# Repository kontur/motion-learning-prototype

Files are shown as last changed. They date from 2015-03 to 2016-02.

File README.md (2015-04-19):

#Motion learning
Prototype for wearable device enhancing motion based learning through sensory feedback.

The idea of this wearable device is to allow the wearer to rely on a multitude of additional sensory information when learning or repeating physical motion. This prototype is designed as a wrist-worn band that gives light, sound and vibration feedback.

Furthermore, the planned desktop interface allows users to record, compare and visualize their movement patterns.

##WIP
Codebase and physical design currently heavily WIP.

##Credits
Many parts of this project are based on open software or hardware. Arduino, Processing and Eagle have been used for the various aspects of the project. In more details:

* The led shield uses the [Adafruit PWM servo driver library](https://github.com/adafruit/Adafruit-PWM-Servo-Driver-Library)
* The Sparkfun IMU shields and their libraries [LSM9](https://github.com/sparkfun/LSM9DS0_Breakout) and [6DoF](https://github.com/sparkfun/IMU_Digital_Combo_Board)
* The project uses [this](http://bildr.org/2012/03/stable-orientation-digital-imu-6dof-arduino/) modification of [Varesano's FreeIMU](www.varesano.net/projects/hardware/FreeIMU) libraries for motion sensor reading
* [HSBColor](https://github.com/julioterra/HSB_Color) library for Arduino for color conversions
* [Toxiclibs](http://toxiclibs.org/) was used on the Processing visualization
* [controlP5](http://www.sojamo.de/libraries/controlP5/) was used in the Processing interface
* [Javastat](http://www2.thu.edu.tw/~wenwei/javastat/doc/) libraries were used for some portions in the software dealing with comparing motion patterns

###Authors
Johannes Neumeier, Jana Pejoska

###Acknowledgments
Project created in spring 2015 at Aalto Media Lab, in the course Prototyping Experience under guidance from Michihito Mizutani.

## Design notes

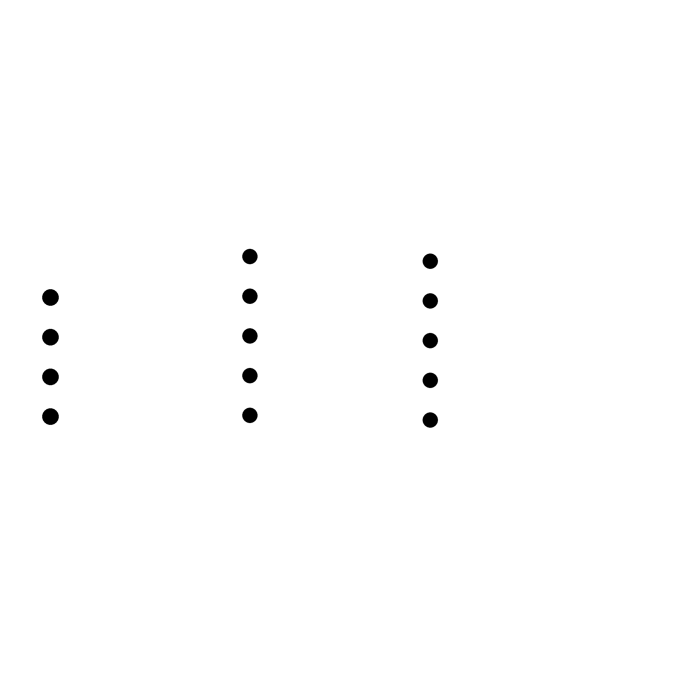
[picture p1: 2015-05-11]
eagle/ledshields_v2/_drill.png

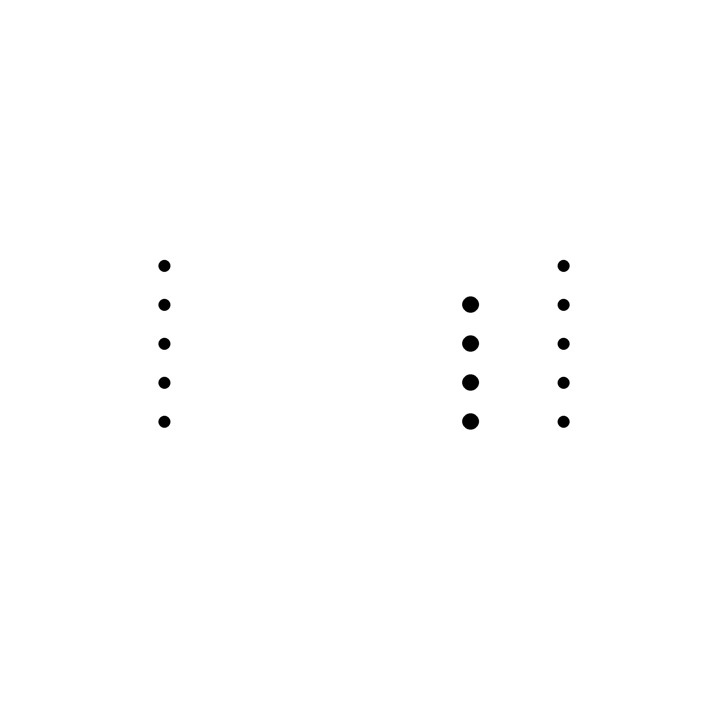
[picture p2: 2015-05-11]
eagle/ledshield/drill.png

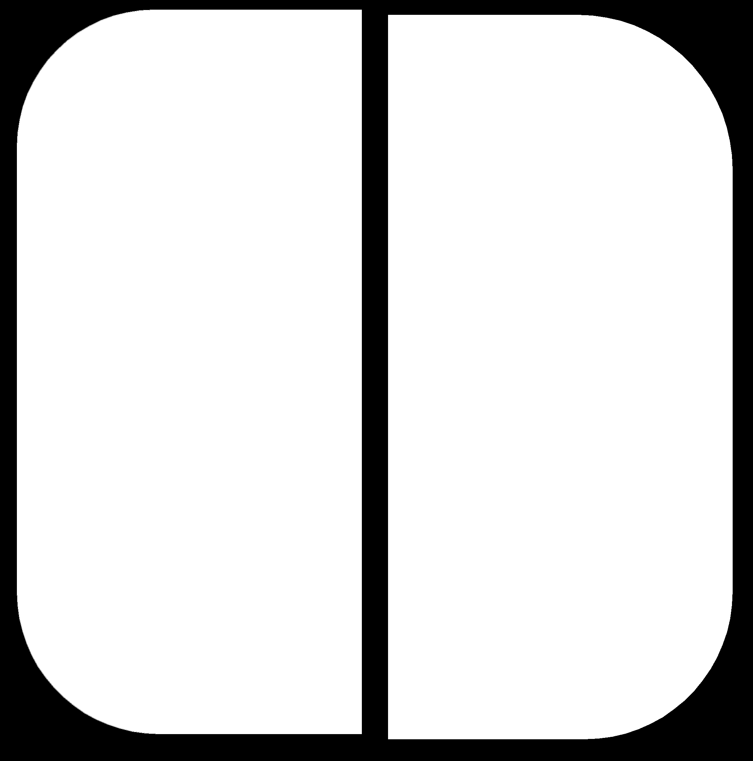
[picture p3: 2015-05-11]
eagle/ledshields_v2/_cut.png

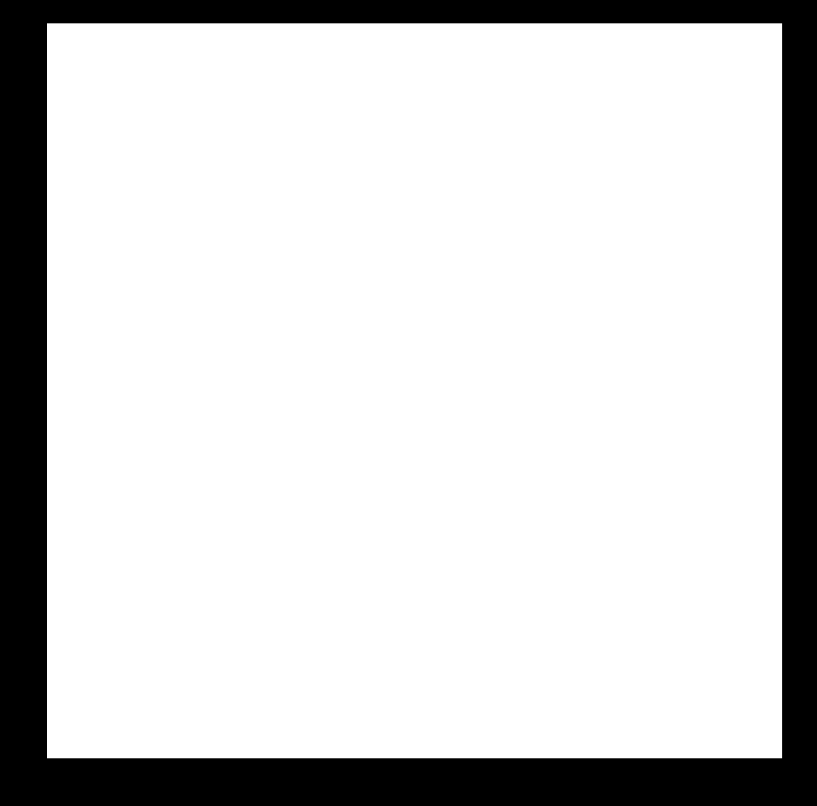
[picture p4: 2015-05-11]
eagle/ledshield/dimension.png

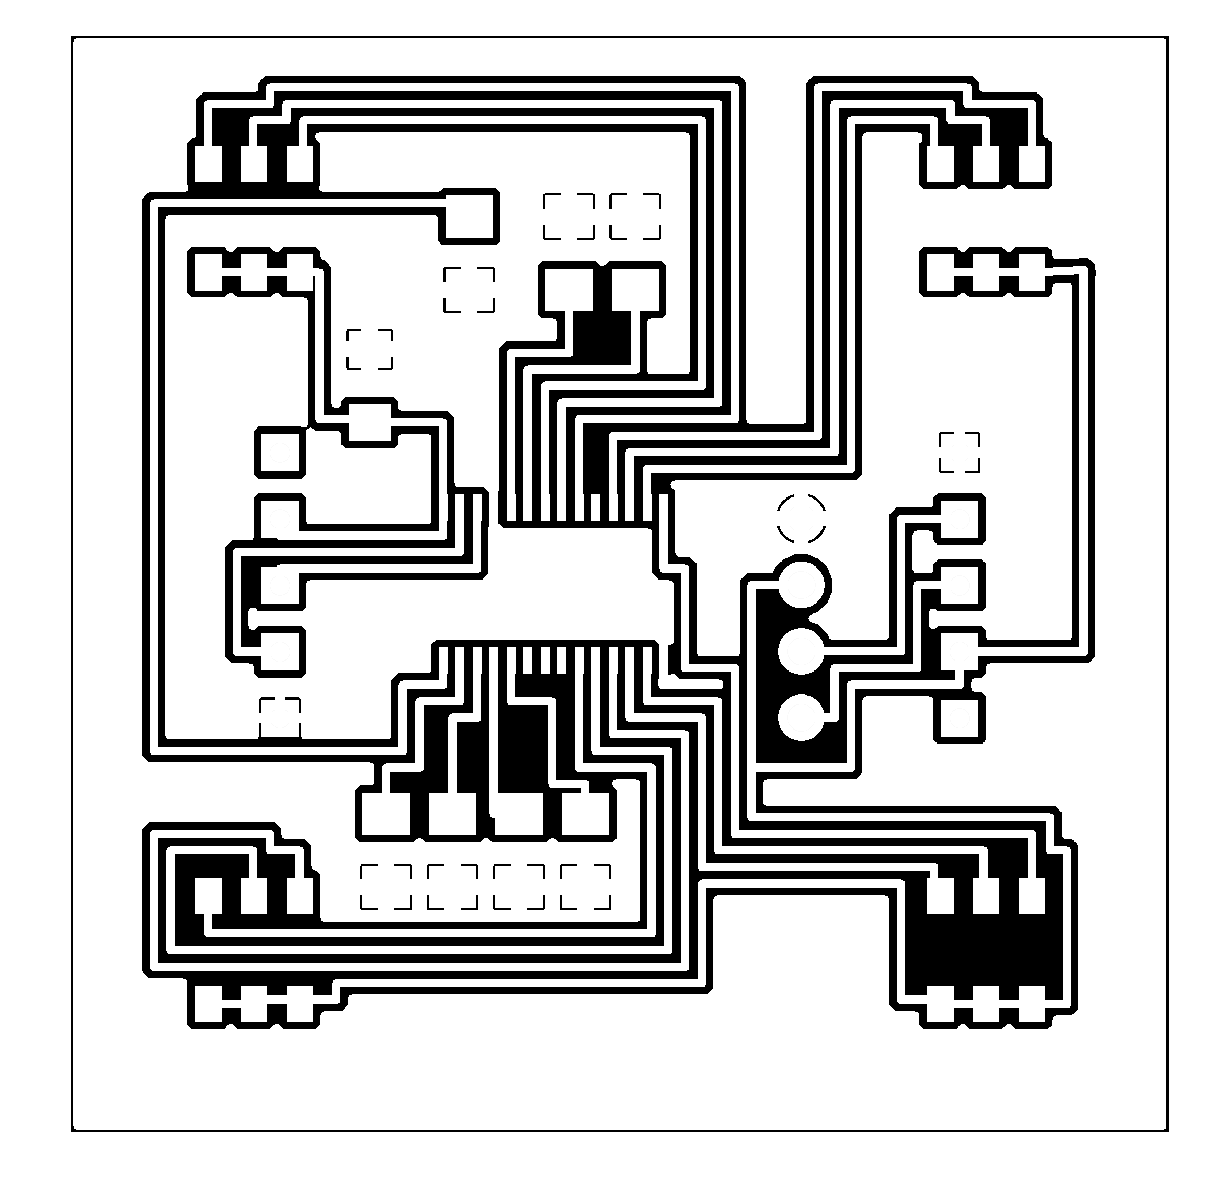
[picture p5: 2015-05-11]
eagle/ledshield/top_0mm3.png

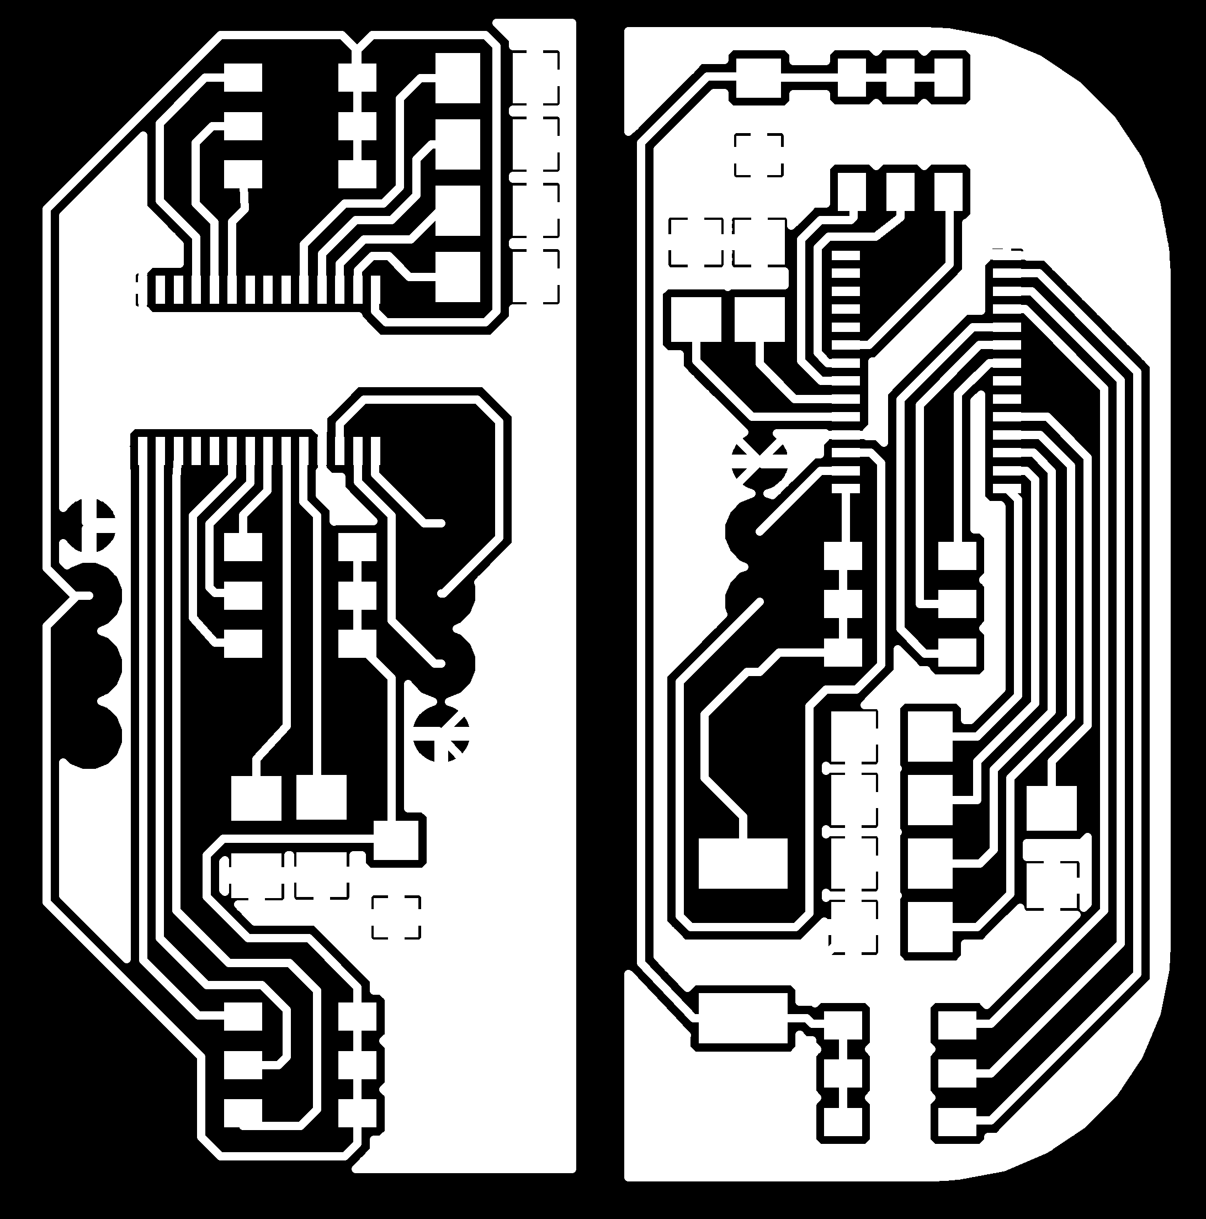
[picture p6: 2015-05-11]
eagle/ledshields_v2/_traces.png

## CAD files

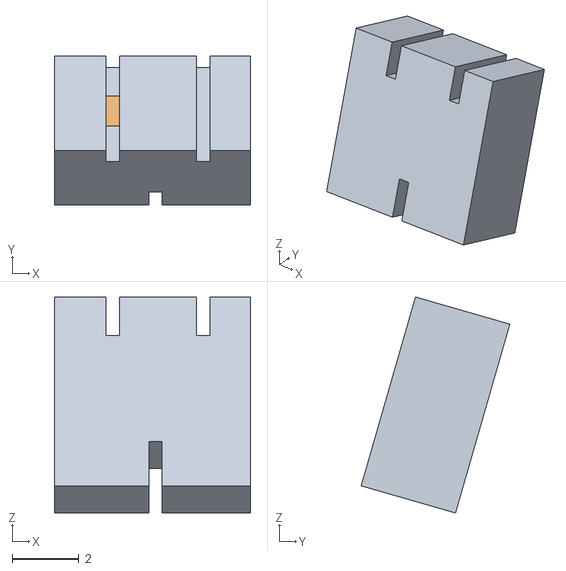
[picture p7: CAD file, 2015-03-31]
processing/Kinemata/data/dma.obj
5.87 x 4.44 x 6.45
polySurface3_group1

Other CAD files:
eagle/kinemata/110mAhBattery.dxf

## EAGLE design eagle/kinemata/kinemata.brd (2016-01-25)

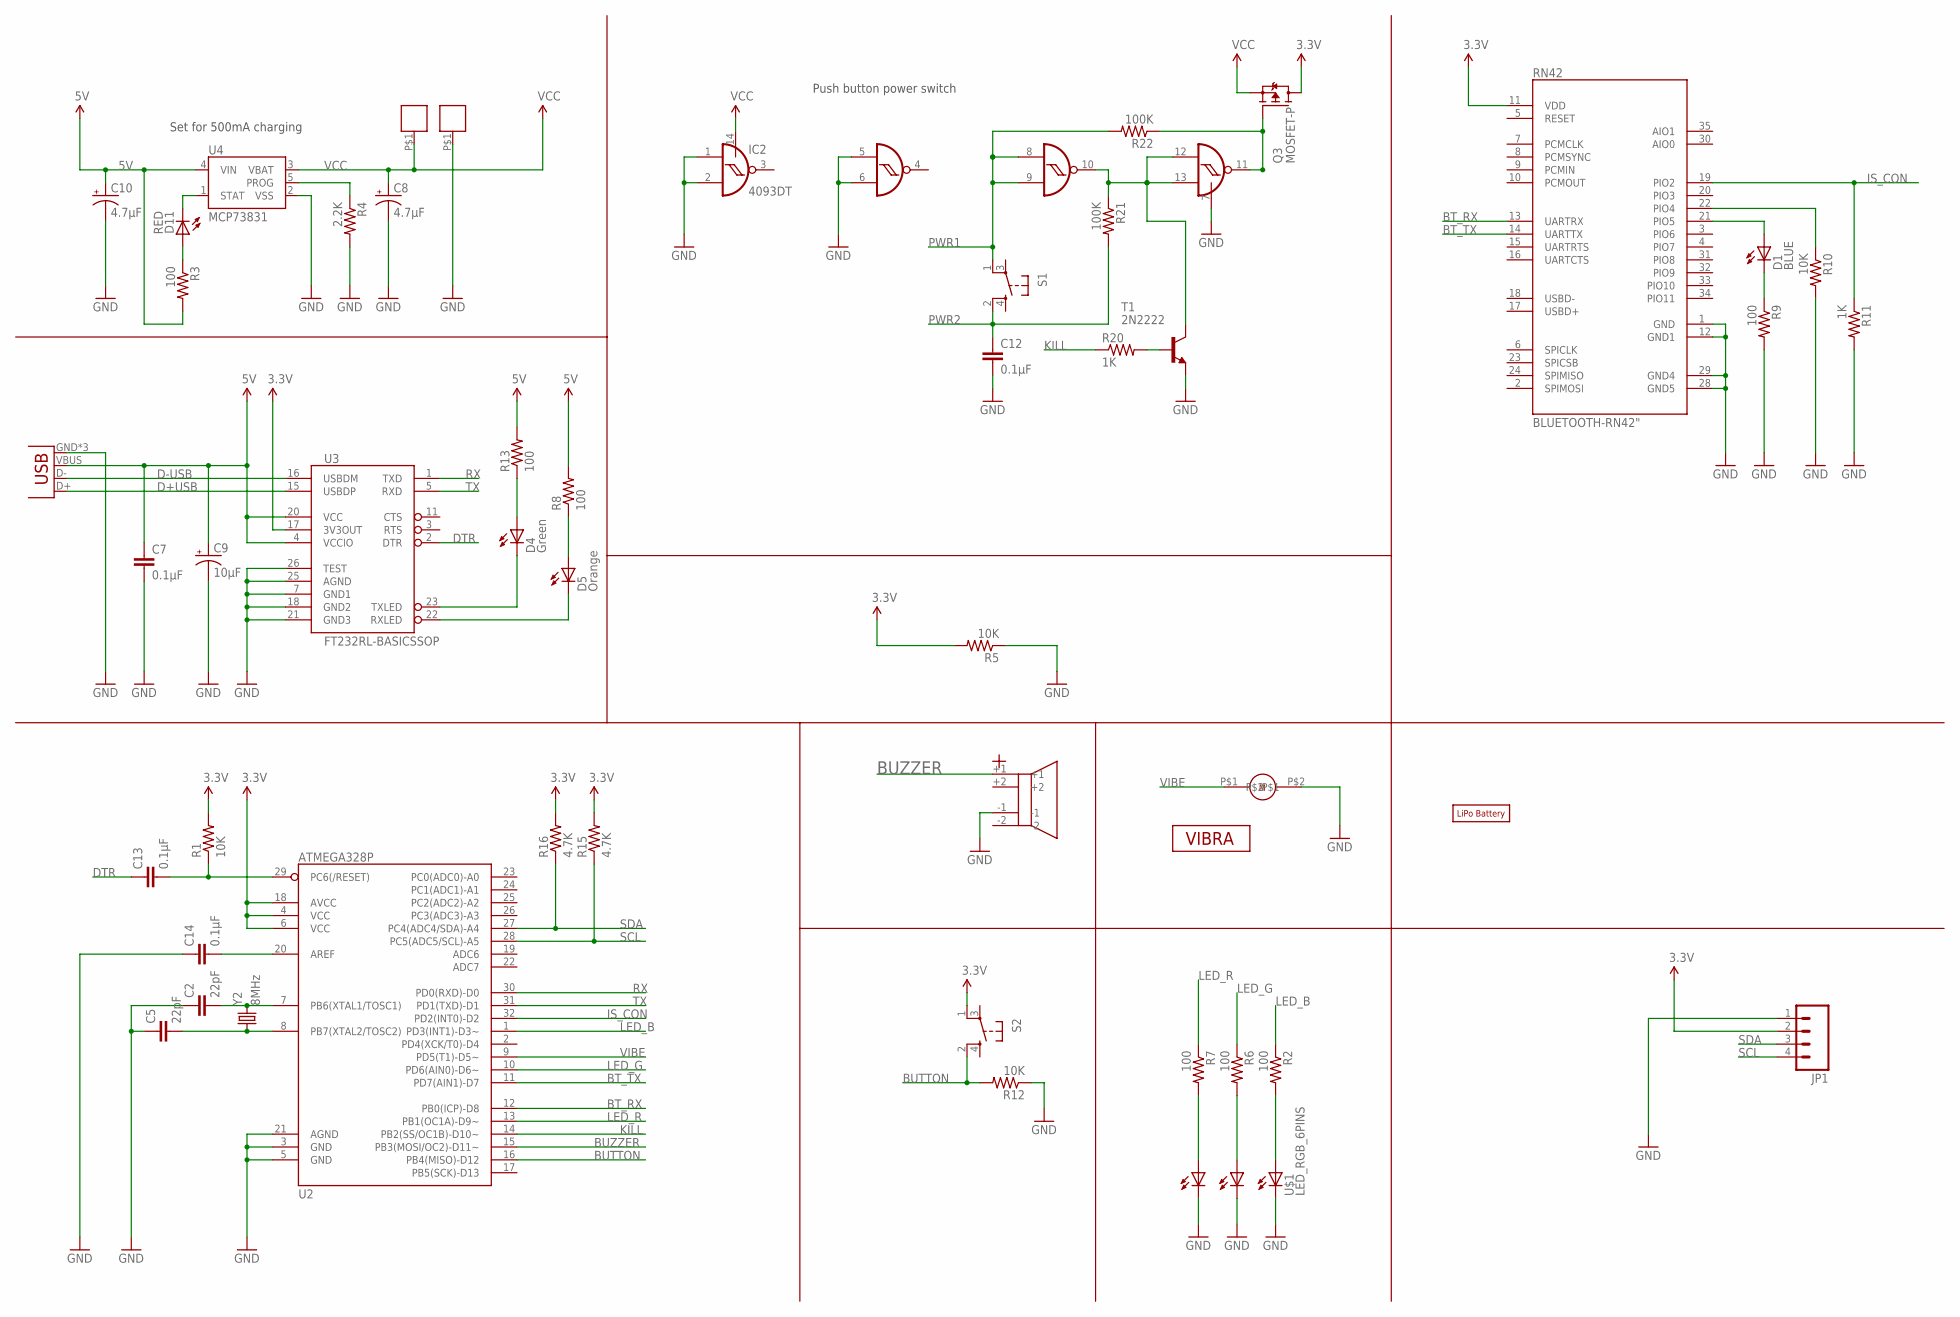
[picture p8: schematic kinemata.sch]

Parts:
BAT+2: LIPO_PAD
BAT-1: LIPO_PAD
C2, C5: 22pF; 1206
C7, C12, C13, C14: 0.1µF; 1206
C8, C10: 4.7µF; EIA3216
C9: 10µF; EIA3216
D1: BLUE; LED-1206
D4: Green; LED-1206
D5: Orange; LED-1206
D11: RED; LED-1206
IC2: 4093DT; MC14093B-TSSOP14
JP1: M04LONGPADS; 1X04_LONGPADS
JP6: USB-MICROB
Q3: MOSFET-P; SOT23
R1, R5, R10, R12: 10K; 1206
R2, R3, R6, R7, R8, R9, R13: 100; 1206
R4: 2.2K; 1206
R11, R20: 1K; 1206
R15, R16: 4.7K; 1206
R21, R22: 100K; 1206
RN42: BLUETOOTH-RN42"; RN42
S1, S2: TAC_SWITCH_SIDEWAY; TACTILE_SWITCH_ANGLE_SMD
T1: 2N2222; TO92-EBC-OVAL
U2: ATMEGA328P; TQFP32-08
U3: FT232RL-BASICSSOP; SSOP28DB
U4: MCP73831; SOT23-5
U$1: LED_RGB_6PINS
U$2: LIPO_BATTERY110MAH; LIPO_BATTERY_110MAH
U$3: BUZZER_4PINS; FARNELL_BUZZER_MAGNETIC_SMD_3V_2215091
U$4: VIBRATION_MOTOR_SHAPE
U$5: VIBRATION_MOTOR; VIBRATION_MOTOR_CABLE
Y2: 8MHz; CRYSTAL_8MHZ_SMD_FARNELL_2101329

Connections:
3.3V: JP1.2, Q3.3 (D), R1.2, R5.2, R15.2, R16.2, RN42.11 (VDD), S2.1 (A2), U2.4 (VCC), U2.6 (VCC), U2.18 (AVCC), U3.17 (3V3OUT)
5V: C7.1, C9.A (+), C10.A (+), JP6.VBUS, R3.2, R8.2, R13.2, U3.4 (VCCIO), U3.20 (VCC), U4.4 (VIN)
BT_RX: RN42.13 (UARTRX), U2.12 (PB0(ICP)-D8)
BT_TX: RN42.14 (UARTTX), U2.11 (PD7(AIN1)-D7)
BUTTON: R12.2, S2.2 (B2), U2.16 (PB4(MISO)-D12)
BUZZER: U2.15 (PB3(MOSI/OC2)-D11~), U$3.+1
D+USB: JP6.D+, U3.15 (USBDP)
D-USB: JP6.D-, U3.16 (USBDM)
DTR: C13.1, U3.2 (DTR)
GND: BAT-1.P$1, C2.1, C5.1, C7.2, C8.C (-), C9.C (-), C10.C (-), C12.2, C14.1, IC2.1, IC2.2, IC2.5, IC2.6, IC2.7, JP1.1, JP6.GND, JP6.MT1 (GND), JP6.MT2 (GND), R4.2, R5.1, R9.2, R10.2, R11.2, R12.1, RN42.1 (GND), RN42.12 (GND1), RN42.28 (GND5), RN42.29 (GND4), T1.E, U2.3 (GND), U2.5 (GND), U2.21 (AGND), U3.7 (GND1), U3.18 (GND2), U3.21 (GND3), U3.25 (AGND), U3.26 (TEST), U4.2 (VSS), U$1.BC, U$1.GC, U$1.RC, U$3.-1, U$5.P$2
IS_CON: R11.1, RN42.19 (PIO2), U2.32 (PD2(INT0)-D2)
KILL: R20.1, U2.14 (PB2(SS/OC1B)-D10~)
LED_B: R2.1, U2.1 (PD3(INT1)-D3~)
LED_G: R6.1, U2.10 (PD6(AIN0)-D6~)
LED_R: R7.1, U2.13 (PB1(OC1A)-D9~)
unnamed: R7.2, U$1.BA
unnamed: R2.2, U$1.GA
unnamed: D11.A, R3.1
unnamed: R6.2, U$1.RA
unnamed: D4.A, R13.1
unnamed: D5.A, R8.1
unnamed: R10.1, RN42.22 (PIO4)
unnamed: D1.A, RN42.21 (PIO5)
unnamed: C5.2, U2.8 (PB7(XTAL2/TOSC2)), Y2.P$1 (1)
unnamed: C2.2, U2.7 (PB6(XTAL1/TOSC1)), Y2.P$2 (2)
unnamed: D1.C, R9.1
unnamed: C13.2, R1.1, U2.29 (PC6(/RESET))
unnamed: C14.2, U2.20 (AREF)
unnamed: IC2.10, IC2.12, IC2.13, R21.1, T1.C
unnamed: R20.2, T1.B
unnamed: IC2.11, Q3.1 (G), R22.1
PROG: R4.1, U4.5 (PROG)
PWR1: IC2.8, IC2.9, R22.2, S1.1 (A2)
PWR2: C12.1, R21.2, S1.2 (B2)
RX: U2.30 (PD0(RXD)-D0), U3.1 (TXD)
RXLED: D5.C, U3.22 (RXLED)
SCL: JP1.4, R15.1, U2.28 (PC5(ADC5/SCL)-A5)
SDA: JP1.3, R16.1, U2.27 (PC4(ADC4/SDA)-A4)
STAT: D11.C, U4.1 (STAT)
TX: U2.31 (PD1(TXD)-D1), U3.5 (RXD)
TXLED: D4.C, U3.23 (TXLED)
VCC: BAT+2.P$1, C8.A (+), IC2.14, Q3.2 (S), U4.3 (VBAT)
VIBE: U2.9 (PD5(T1)-D5~), U$5.P$1

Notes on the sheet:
Set for 500mA charging
Push button power switch

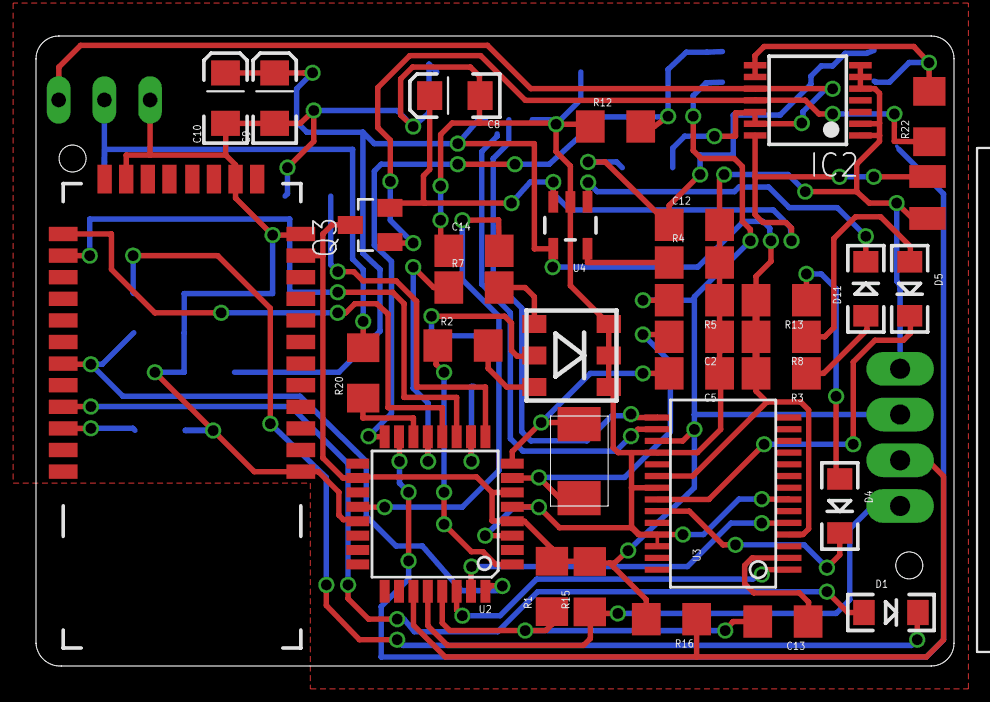
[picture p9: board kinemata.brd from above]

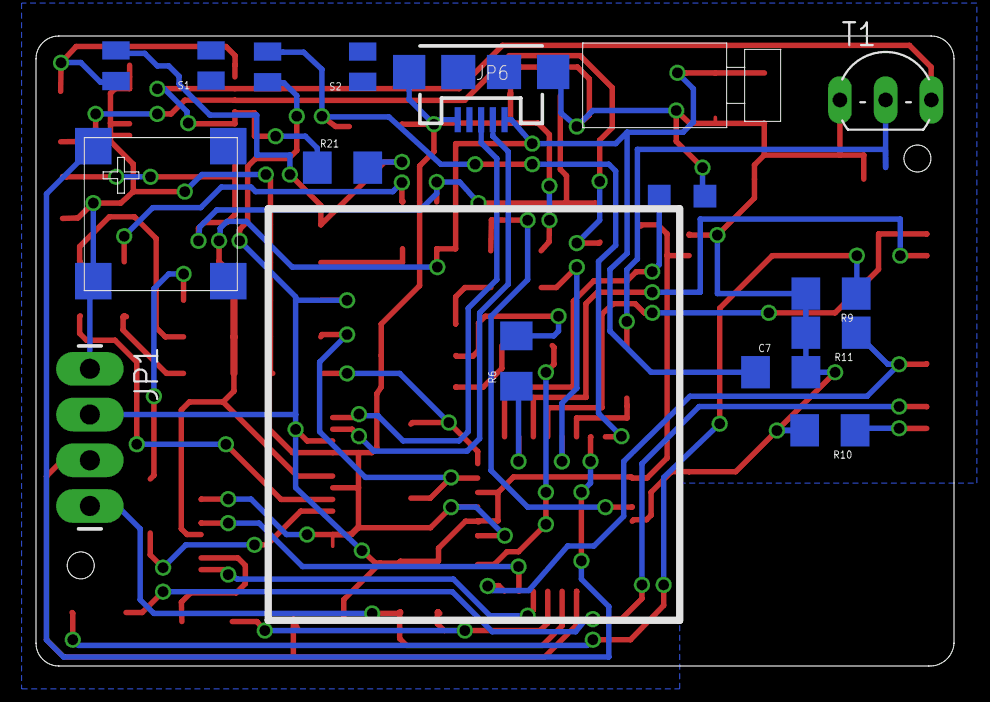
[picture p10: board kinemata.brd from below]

Board: 2 copper layers, 51.0 x 35.0 mm, 50 parts (14 on the bottom side), 43 nets.

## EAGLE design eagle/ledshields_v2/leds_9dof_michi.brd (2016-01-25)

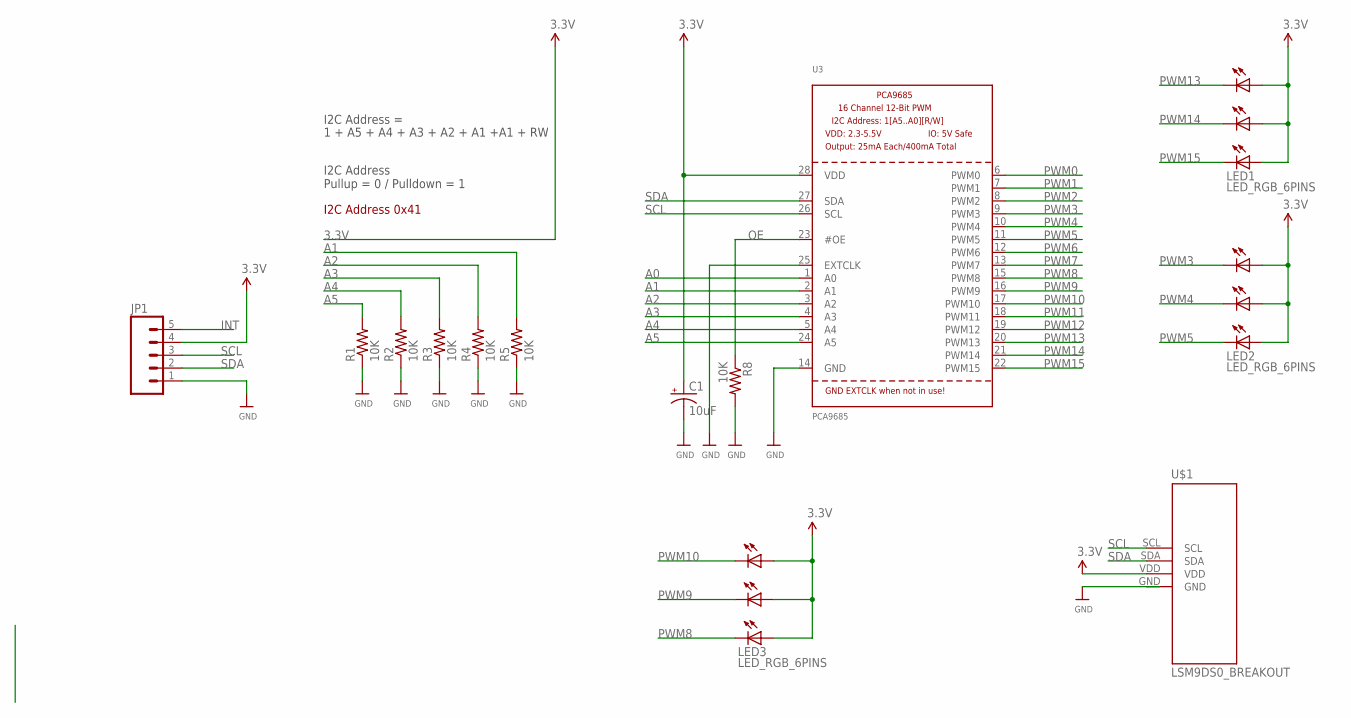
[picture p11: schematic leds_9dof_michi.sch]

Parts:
C1: 10uF; EIA3216
JP1: M05PTH; 1X05
LED1, LED2, LED3: LED_RGB_6PINS
R1, R2, R3, R4, R5, R8: 10K; 1206
U3: PCA9685; TSSOP28
U$1: LSM9DS0_BREAKOUT

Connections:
3.3V: C1.A (+), JP1.4, LED1.BA, LED1.GA, LED1.RA, LED2.BA, LED2.GA, LED2.RA, LED3.BA, LED3.GA, LED3.RA, U3.28 (VDD), U$1.VDD
A0: U3.1 (A0)
A1: R5.2, U3.2 (A1)
A2: R4.2, U3.3 (A2)
A3: R3.2, U3.4 (A3)
A4: R2.2, U3.5 (A4)
A5: R1.2, U3.24 (A5)
GND: C1.C (-), JP1.1, R1.1, R2.1, R3.1, R4.1, R5.1, R8.2, U3.14 (GND), U3.25 (EXTCLK), U$1.GND
INT: JP1.5
OE: R8.1, U3.23 (#OE)
PWM0: U3.6 (PWM0)
PWM1: U3.7 (PWM1)
PWM2: U3.8 (PWM2)
PWM3: LED2.BC, U3.9 (PWM3)
PWM4: LED2.RC, U3.10 (PWM4)
PWM5: LED2.GC, U3.11 (PWM5)
PWM6: U3.12 (PWM6)
PWM7: U3.13 (PWM7)
PWM8: LED3.GC, U3.15 (PWM8)
PWM9: LED3.RC, U3.16 (PWM9)
PWM10: LED3.BC, U3.17 (PWM10)
PWM11: U3.18 (PWM11)
PWM12: U3.19 (PWM12)
PWM13: LED1.BC, U3.20 (PWM13)
PWM14: LED1.RC, U3.21 (PWM14)
PWM15: LED1.GC, U3.22 (PWM15)
SCL: JP1.3, U3.26 (SCL), U$1.SCL
SDA: JP1.2, U3.27 (SDA), U$1.SDA

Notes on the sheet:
1 + A5 + A4 + A3 + A2 + A1 +A1 + RW
I2C Address =
I2C Address Pullup = 0 / Pulldown = 1
I2C Address 0x41

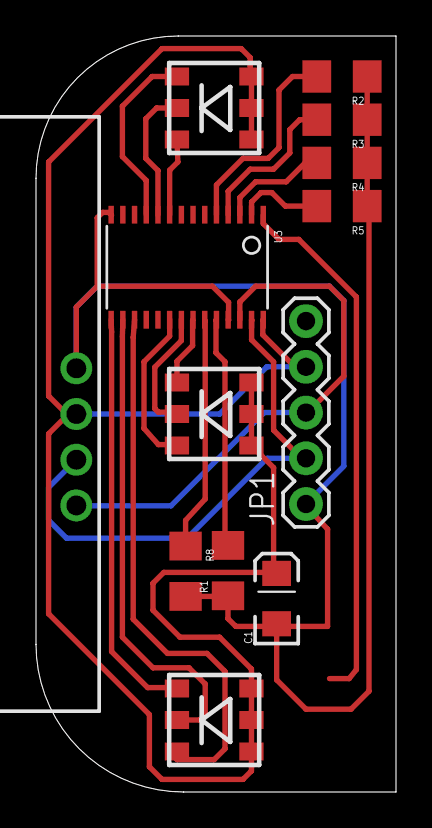
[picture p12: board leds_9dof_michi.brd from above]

Board: 2 copper layers, 20.0 x 42.0 mm, 13 parts (0 on the bottom side), 19 nets.

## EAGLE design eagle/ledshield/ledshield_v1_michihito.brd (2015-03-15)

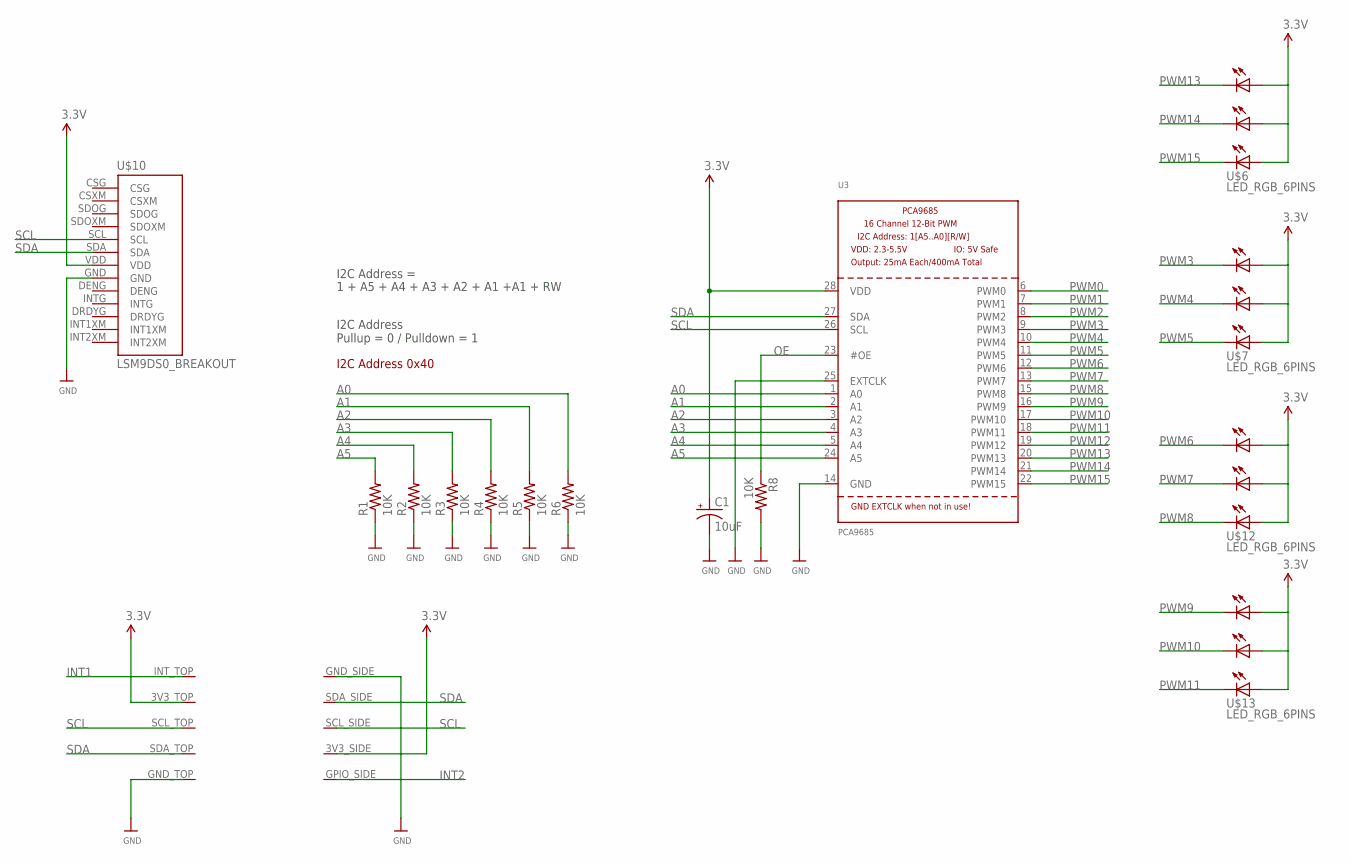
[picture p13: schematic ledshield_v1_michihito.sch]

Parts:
C1: 10uF; EIA3216
R1, R2, R3, R4, R5, R6, R8: 10K; 1206
U3: PCA9685; TSSOP28
U$1: IOT_MODULE_MAIN_V2_PTH; IOT_MODULE_MAIN_V3_PTH
U$6, U$7, U$12, U$13: LED_RGB_6PINS
U$10: LSM9DS0_BREAKOUT

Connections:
3.3V: C1.A (+), U3.28 (VDD), U$1.3V3_SIDE, U$1.3V3_TOP, U$6.BA, U$6.GA, U$6.RA, U$7.BA, U$7.GA, U$7.RA, U$10.VDD, U$12.BA, U$12.GA, U$12.RA, U$13.BA, U$13.GA, U$13.RA
A0: R6.2, U3.1 (A0)
A1: R5.2, U3.2 (A1)
A2: R4.2, U3.3 (A2)
A3: R3.2, U3.4 (A3)
A4: R2.2, U3.5 (A4)
A5: R1.2, U3.24 (A5)
GND: C1.C (-), R1.1, R2.1, R3.1, R4.1, R5.1, R6.1, R8.2, U3.14 (GND), U3.25 (EXTCLK), U$1.GND_SIDE, U$1.GND_TOP, U$10.GND
INT1: U$1.INT_TOP
INT2: U$1.GPIO_SIDE
OE: R8.1, U3.23 (#OE)
PWM0: U3.6 (PWM0)
PWM1: U3.7 (PWM1)
PWM2: U3.8 (PWM2)
PWM3: U3.9 (PWM3), U$7.BC
PWM4: U3.10 (PWM4), U$7.RC
PWM5: U3.11 (PWM5), U$7.GC
PWM6: U3.12 (PWM6), U$12.BC
PWM7: U3.13 (PWM7), U$12.RC
PWM8: U3.15 (PWM8), U$12.GC
PWM9: U3.16 (PWM9), U$13.BC
PWM10: U3.17 (PWM10), U$13.RC
PWM11: U3.18 (PWM11), U$13.GC
PWM12: U3.19 (PWM12)
PWM13: U3.20 (PWM13), U$6.BC
PWM14: U3.21 (PWM14), U$6.RC
PWM15: U3.22 (PWM15), U$6.GC
SCL: U3.26 (SCL), U$1.SCL_SIDE, U$1.SCL_TOP, U$10.SCL
SDA: U3.27 (SDA), U$1.SDA_SIDE, U$1.SDA_TOP, U$10.SDA

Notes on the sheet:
1 + A5 + A4 + A3 + A2 + A1 +A1 + RW
I2C Address =
I2C Address Pullup = 0 / Pulldown = 1
I2C Address 0x40

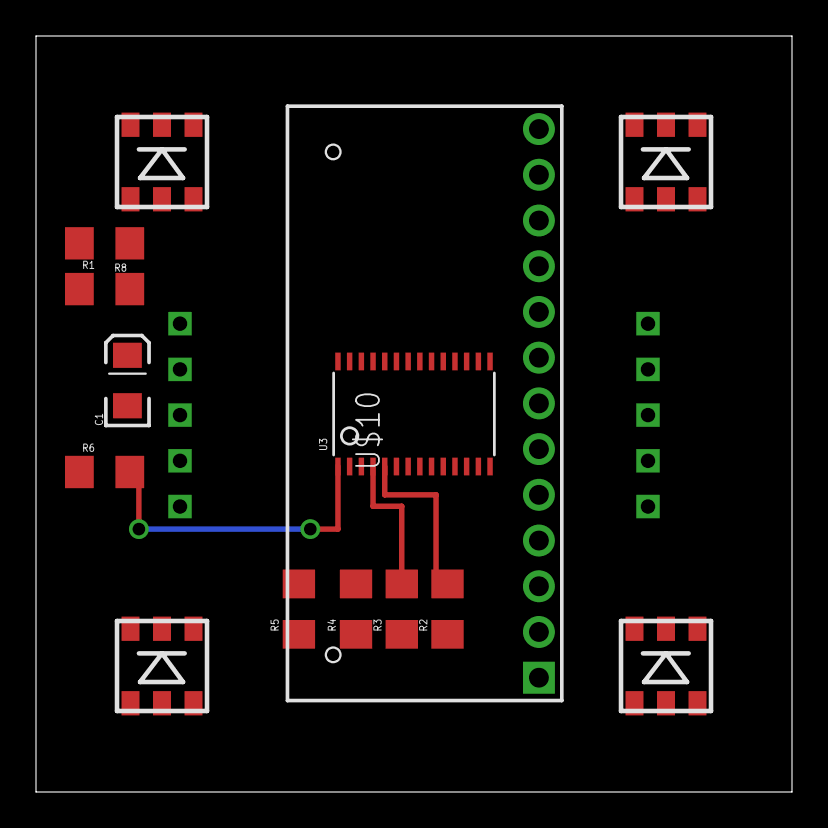
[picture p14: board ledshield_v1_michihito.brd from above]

Board: 2 copper layers, 42.0 x 42.0 mm, 15 parts (0 on the bottom side), 23 nets.

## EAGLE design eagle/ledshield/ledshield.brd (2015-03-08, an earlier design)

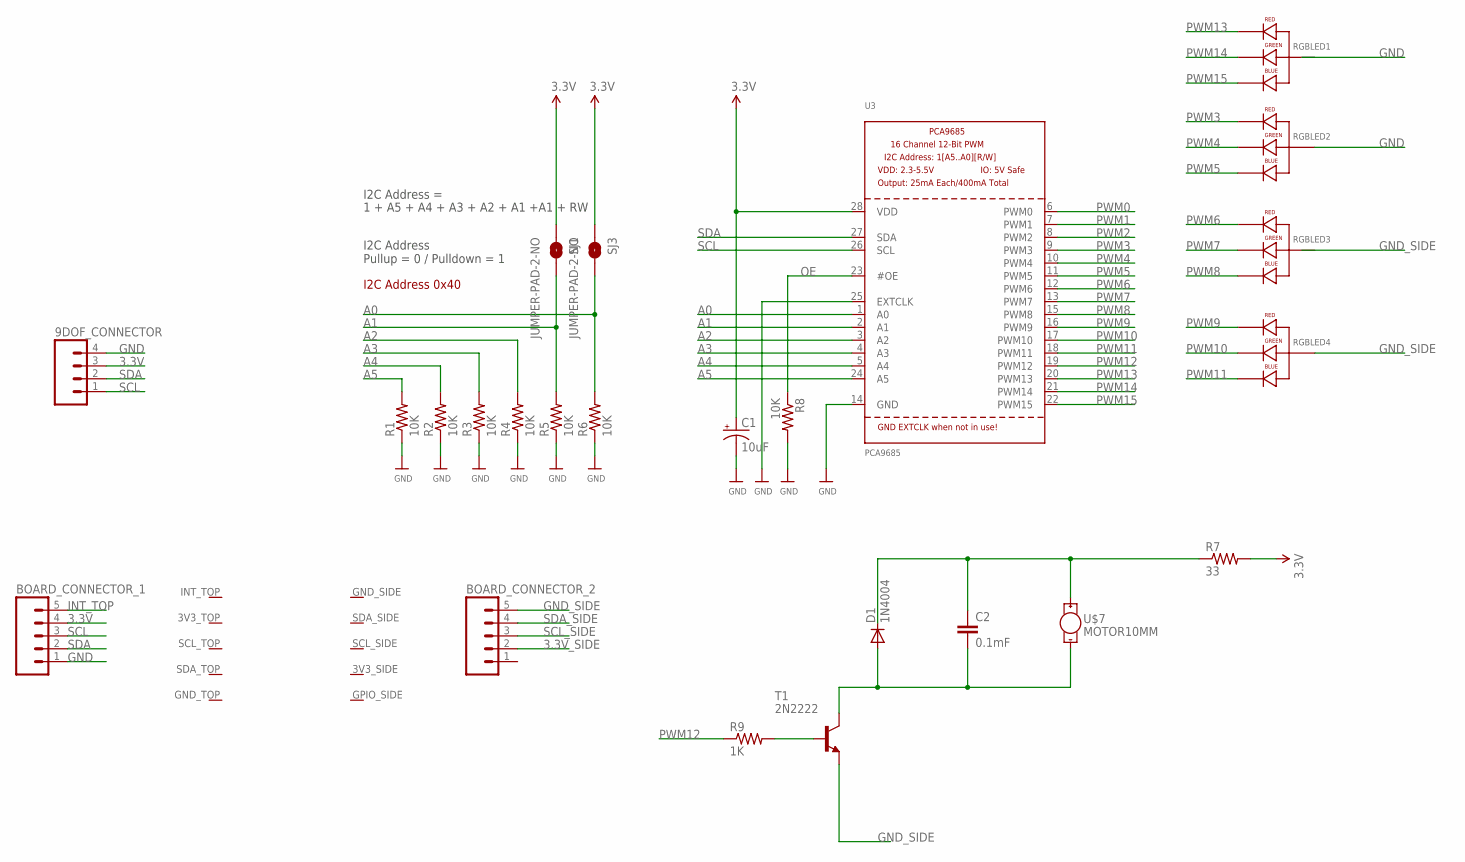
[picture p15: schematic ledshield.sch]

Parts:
9DOF_CONNECTOR: M041.27MM; 1X04-1.27MM
BOARD_CONNECTOR_1, BOARD_CONNECTOR_2: M051.27MM; 1X05-1.27MM
C1: 10uF; EIA3216
C2: 0.1mF; 1206
D1: 1N4004; DO41-10
R1, R2, R3, R4, R5, R6, R8: 10K; 1206
R7: 33; 1206
R9: 1K; 1206
RGBLED1, RGBLED2, RGBLED3, RGBLED4: LED-RGB-CA-THRUCLEAR; LED-RGB-THRU
SJ1, SJ3: JUMPER-PAD-2-NO; PAD-JUMPER-2-NO_NO_SILK
T1: 2N2222; TO92-EBC-OVAL
U3: PCA9685; TSSOP28
U$1: IOT_MODULE_MAIN_V2_PTH; IOT_MODULE_MAIN_V3_PTH
U$7: MOTOR10MM; VIBE-MOTOR-10MM

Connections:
3.3V: 9DOF_CONNECTOR.3, BOARD_CONNECTOR_1.4, C1.A (+), R7.2, SJ1.1, SJ3.1, U3.28 (VDD)
3.3V_SIDE: BOARD_CONNECTOR_2.2
A0: R6.2, SJ3.2, U3.1 (A0)
A1: R5.2, SJ1.2, U3.2 (A1)
A2: R4.2, U3.3 (A2)
A3: R3.2, U3.4 (A3)
A4: R2.2, U3.5 (A4)
A5: R1.2, U3.24 (A5)
GND: 9DOF_CONNECTOR.4, BOARD_CONNECTOR_1.1, C1.C (-), R1.1, R2.1, R3.1, R4.1, R5.1, R6.1, R8.2, RGBLED2.2 (ANODE), U3.14 (GND), U3.25 (EXTCLK)
GND_SIDE: BOARD_CONNECTOR_2.5, RGBLED4.2 (ANODE), T1.E
INT_TOP: BOARD_CONNECTOR_1.5
unnamed: C2.1, D1.C, R7.1, U$7.+
unnamed: C2.2, D1.A, T1.C, U$7.-
unnamed: R9.2, T1.B
OE: R8.1, U3.23 (#OE)
PWM0: U3.6 (PWM0)
PWM1: U3.7 (PWM1)
PWM2: U3.8 (PWM2)
PWM3: RGBLED2.1 (RED_CATHODE), U3.9 (PWM3)
PWM4: RGBLED2.3 (GREEN_CATHODE), U3.10 (PWM4)
PWM5: RGBLED2.4 (BLUE_CATHODE), U3.11 (PWM5)
PWM6: RGBLED3.1 (RED_CATHODE), U3.12 (PWM6)
PWM7: RGBLED3.3 (GREEN_CATHODE), U3.13 (PWM7)
PWM8: RGBLED3.4 (BLUE_CATHODE), U3.15 (PWM8)
PWM9: RGBLED4.1 (RED_CATHODE), U3.16 (PWM9)
PWM10: RGBLED4.3 (GREEN_CATHODE), U3.17 (PWM10)
PWM11: RGBLED4.4 (BLUE_CATHODE), U3.18 (PWM11)
PWM12: R9.1, U3.19 (PWM12)
PWM13: RGBLED1.1 (RED_CATHODE), U3.20 (PWM13)
PWM14: RGBLED1.3 (GREEN_CATHODE), U3.21 (PWM14)
PWM15: RGBLED1.4 (BLUE_CATHODE), U3.22 (PWM15)
SCL: 9DOF_CONNECTOR.1, BOARD_CONNECTOR_1.3, U3.26 (SCL)
SCL_SIDE: BOARD_CONNECTOR_2.3
SDA: 9DOF_CONNECTOR.2, BOARD_CONNECTOR_1.2, U3.27 (SDA)
SDA_SIDE: BOARD_CONNECTOR_2.4

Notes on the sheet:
1 + A5 + A4 + A3 + A2 + A1 +A1 + RW
I2C Address =
I2C Address Pullup = 0 / Pulldown = 1
I2C Address 0x40

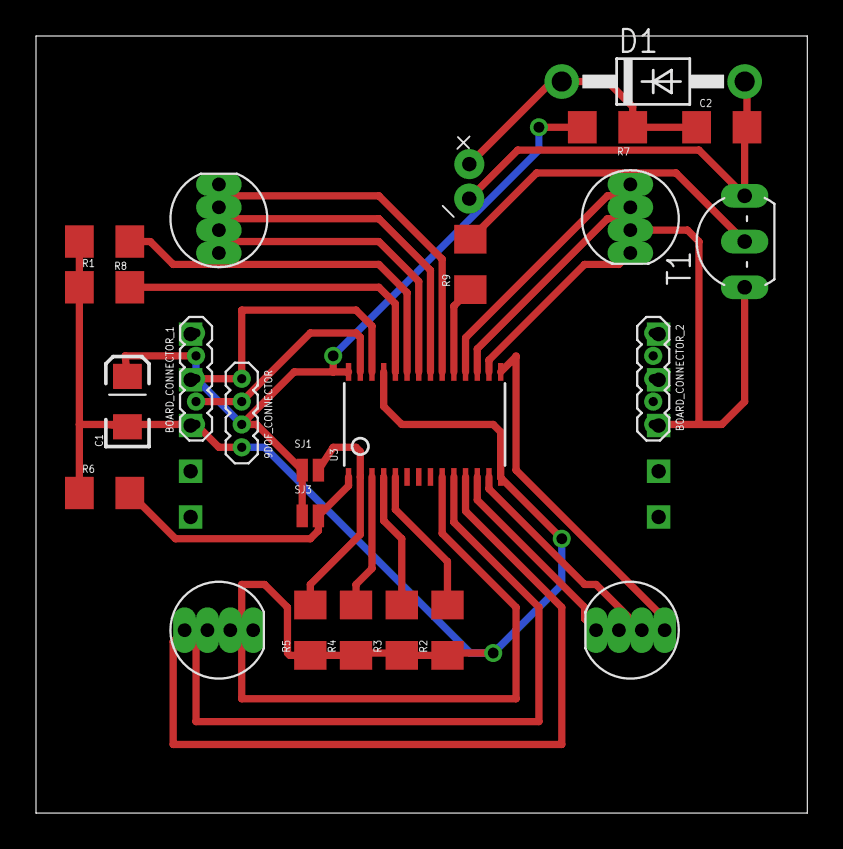
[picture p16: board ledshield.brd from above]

Board: 2 copper layers, 42.9 x 43.2 mm, 25 parts (0 on the bottom side), 28 nets.

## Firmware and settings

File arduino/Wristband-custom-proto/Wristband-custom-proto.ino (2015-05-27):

// interfacing libraries
#include <SPI.h>
#include <SoftwareSerial.h>
#include <Wire.h>

// math helpers
#include <math.h>

// variable size arrays with push and pop
#include <StackArray.h>

// convenient RGB HSL
#include <HSBColor.h>

// 9DoF driver
#include <SFE_LSM9DS0.h>

// PWM module driver for leds
#include <Adafruit_PWMServoDriver.h>

// defined shortcuts for notes with common musical names
#include "pitches.h"

// 9 DOF setup
#define LSM9DS0_XM  0x1D // Would be 0x1E if SDO_XM is LOW
#define LSM9DS0_G   0x6B // Would be 0x6A if SDO_G is LOW
LSM9DS0 dof(MODE_I2C, LSM9DS0_G, LSM9DS0_XM);
#define PRINT_CALCULATED
#define PRINT_SPEED 500 // ms between prints?

// PWM setup
Adafruit_PWMServoDriver pwmR = Adafruit_PWMServoDriver(0x40);
Adafruit_PWMServoDriver pwmL = Adafruit_PWMServoDriver(0x41);

const int baudrate = 9600;

// PINS
const int onBoardLedPin = 6;
const int vibrationPin = 5;
const int buzzerPin = 11;
const int buttonPin = 12;

// Bluetooth connection pins and serial
const int rx = 7;
const int tx = 8;
SoftwareSerial mySerial(rx, tx);

// tracking button pressed stated
int button = 0;
int lastButton = 0;

// desired fps rate between loops
// NOTE that this is in reality MUCH lower, ~4 fps
float fps = 12;
float msPerFrame = 1000 / fps; // ~83


// variables for saving the previous frame's readings
int lastRoll = 0;
int lastHeading = 0;
int lastPitch = 0;
int lastRotation = 0;

// arrays holding the last sensor readings per axis
float lastAccel[3];
float lastGyro[3];
float lastMag[3];

// arrays holding the percentual change of sensor readings between loops
float changeAccel[3] = { 0, 0, 0 };
float changeGyro[3] = { 0, 0, 0 };
float changeMag[3] = { 0, 0, 0 };

// absolute upper peaks for each sensor value
// gets dynamically increased when new peaks are reached
// NOTE: these values are conservative estimates and intentionally low enough to dynamically
// get increased on use; this also means the device needs some "wild movement" calibration
// after startup
float maxAccel[3] = { 1, 1, 1 };
float maxGyro[3] = { 200, 200, 200 };
float maxMag[3] = { 0.25, 0.25, 0.25 };

float easing = 0.75; // 0 - 1 as factor of "last frame reading" impact on new reading


// rgb color array
int rgbColor[3];

unsigned long now;
unsigned long lastFrame;
unsigned long lastButtonUp = 0;
unsigned long vibrationStart = 0;
unsigned long lastSensorRead = 0;

int framesSinceSensorRead = 0;

// in loop variables
// declared outside the loop and reused to save initialization every loop

// arrays holding the sensor readings
float accel[3];
float gyro[3];
float mag[3];

// variables holding the "calculated" IMU values (note, orientation is a helper to get pitch and roll)
float heading;
float orientation[2];
float pitch;
float roll;

// various combined changes in acceleration and rotation
float combinedAccelerationChange;
float absCombinedAccelerationChange;
float combinedRotationChange;
float absCombinedRotationChange;
float combinedChange;

float threshold = 2.5;



void setup () {
  Serial.begin(115200);
  Serial.println("hello serial");
  mySerial.begin(baudrate);

  uint16_t status = dof.begin();
  Serial.print("LSM9DS0 WHO_AM_I's returned: 0x");
  Serial.println(status, HEX);
  Serial.println("Should be 0x49D4");
  Serial.println();

  // adafruit pwm driver
  pwmR.begin();
  pwmR.setPWMFreq(1600);  // This is the maximum PWM frequency
  pwmL.begin();
  pwmL.setPWMFreq(1600);

  // save I2C bitrate
  uint8_t twbrbackup = TWBR;
  // must be changed after calling Wire.begin() (inside pwm.begin())
  TWBR = 12; // upgrade to 400KHz!

  // turn off on-board led
  analogWrite(onBoardLedPin, LOW);

  setRGBs(0, 0, 0);

  // startup sound
  playSound(5);
}


void loop () {
  Serial.println("---");

  now = millis();

  // register button click if there are any
  // make sure not to register button clicks to "eagerly" so that a single press of the button
  // won't be registered as a double click

  button = digitalRead(buttonPin);
  if (button == 1 && lastButton == 0) {
    sendButtonDown();
  }
  lastButton = button;


  // read bluetooth commands from processing in
  readBluetooth();


  /*
  Serial.print("Actual frame delay since last frame: ");
  float actualFps = now - lastFrame;
  Serial.println(actualFps);
  */

  // this last value is arbitrary and just low enough so that we can read often
  if (lastSensorRead == 0 || (now - lastSensorRead > 100 && framesSinceSensorRead > 3)) {
    //Serial.println("SENSORS**********************");
    readSensors();
    lastSensorRead = now;
    framesSinceSensorRead = 0;
  }

  if (framesSinceSensorRead == 1) {
    setVibration();
  }

  if (framesSinceSensorRead == 2) {
    setLeds();
  }

  if (framesSinceSensorRead == 3) {
    sendJson();
  }


  //if (vibrationStart != 0 && now - vibrationStart > 1000 / fps / 2) {
    
  // this 250 is arbitrary
  if (vibrationStart != 0 && now - vibrationStart > 250) {
    //Serial.println("VIBRATION STOP~~~~");
    analogWrite(vibrationPin, 0);
    vibrationStart = 0;
  }

  // compensate to achieve a delay between frames as close as possible to the actual desired framerate
  float delayUntilNextFrame = min(max(0, msPerFrame - ((now - lastFrame) - msPerFrame)), msPerFrame);
  /*
  Serial.print("Delay until next frame to reach target fps: ");
  Serial.println(delayUntilNextFrame);
  */

  lastFrame = now;

  // always increment, it will start form 0 on sensor read and then be +1 for every frame after
  framesSinceSensorRead++;
  
  delay(delayUntilNextFrame);
}


void readSensors () {

  /*
  Serial.print("0 ");
  Serial.println(millis() - now);
  */

  getAccel(&accel[0]);
  getGyro(&gyro[0]);
  getMag(&mag[0]);
  getHeading(dof.mx, dof.my);
  getOrientation(
    dof.calcAccel(dof.ax),
    dof.calcAccel(dof.ay),
    dof.calcAccel(dof.az),
    &orientation[0]
  );
  pitch = orientation[0];
  roll = orientation[1];

  /*
  Serial.print("1 ");
  Serial.println(millis() - now);
  */
  /*
  // ease the readings for pitch, roll and heading to make them more smooth
  heading = lastHeading * easing + (1 - heading * easing);
  pitch = lastPitch * easing + (1 - pitch * easing);
  roll = lastRoll * easing + (1 - roll * easing);
  */

  // store current values for next round to compare
  lastHeading = heading;
  lastPitch = pitch;
  lastRoll = roll;

  /*
  Serial.print("heading ");
  Serial.println(heading);
  Serial.print("pitch ");
  Serial.println(pitch);
  Serial.print("roll ");
  Serial.println(roll);
  */

  for (int i = 0; i < 3; i++) {
    // ease the new values to contain a portion of the previous value, thus making them less
    // fluctuating at the cost of being slightly less responsive
    accel[i] = lastAccel[i] * easing + (1 - accel[i] * easing);
    gyro[i] = lastGyro[i] * easing + (1 - gyro[i] * easing);
    mag[i] = lastMag[i] * easing + (1 - mag[i] * easing);


    // dynamically readjust edge values for all three sensor readings if the current new reading goes
    // beyond the current edge value
    // note abs() doesn't properly work with floats, so there is slightly less elegant code doing abs()
    // checks and saves
    if (accel[i] > 0 && accel[i] > maxAccel[i] ||
        accel[i] < 0 && accel[i] < -maxAccel[i]) {
      maxAccel[i] = accel[i] > 0 ? accel[i] : -accel[i];
    }
    if (gyro[i] > 0 && gyro[i] > maxGyro[i] ||
        gyro[i] < 0 && gyro[i] < -maxGyro[i]) {
      maxGyro[i] = gyro[i] > 0 ? gyro[i] : -gyro[i];
    }
    if (mag[i] > 0 && mag[i] > maxMag[i] ||
        mag[i] < 0 && mag[i] < -maxMag[i]) {
      maxMag[i] = mag[i] > 0 ? mag[i] : -mag[i];
    }

    /*
    Serial.print("2 ");
    Serial.println(millis() - now);
    */
    /*
    Serial.print("maxAccel ");
    Serial.println(maxAccel[i]);

    Serial.print("maxGyro ");
    Serial.println(maxGyro[i]);

    Serial.print("maxMag ");
    Serial.println(maxMag[i]);
    */

    // calculate the percentual change of the values to last values in regards to the maximum range
    // for that value
    // note that this can go beyond 100%, as a) the max value can increase, and for example the gyro
    // can flip from -200 to 200 degrees... TODO fix this somehow better than by mere easing applied
    // above
    changeAccel[i] = (accel[i] - lastAccel[i]) / maxAccel[i] * 100;
    changeGyro[i] = (gyro[i] - lastGyro[i]) / maxGyro[i] * 100;
    changeMag[i] = (mag[i] - lastMag[i]) / maxMag[i] * 100;

    // store current readings for next loop comparison
    lastAccel[i] = accel[i];
    lastGyro[i] = gyro[i];
    lastMag[i] = mag[i];
  }


  combinedAccelerationChange = changeAccel[0] + changeAccel[1] + changeAccel[2];
  combinedRotationChange = changeGyro[0] + changeGyro[1] + changeGyro[2];

  absCombinedAccelerationChange = combinedAccelerationChange > 0 ? combinedAccelerationChange : -combinedAccelerationChange;
  absCombinedRotationChange = combinedRotationChange > 0 ? combinedRotationChange : -combinedRotationChange;

  combinedChange = absCombinedAccelerationChange + absCombinedRotationChange;

  /*
  Serial.println("---");
  Serial.println(changeAccel[0]);
  Serial.println(changeAccel[1]);
  Serial.println(changeAccel[2]);
  Serial.println("---");
  Serial.println(changeGyro[0]);
  Serial.println(changeGyro[1]);
  Serial.println(changeGyro[2]);
  Serial.println("---");
  Serial.println(changeMag[0]);
  Serial.println(changeMag[1]);
  Serial.println(changeMag[2]);
  Serial.println("---");
  */

  /*
  Serial.println("Combined percentual acceleration change: ");
  Serial.println(combinedAccelerationChange);
  //Serial.println(absCombinedAccelerationChange);

  Serial.println("Combined percentual rotation change: ");
  Serial.println(combinedRotationChange);
  //Serial.println(absCombinedRotationChange);

  */
  /*
  Serial.println("Combined percentual change: ");
  Serial.println(combinedChange);
  */
  
  /*
  Serial.print("3 ");
  Serial.println(millis() - now);
  */
}

void setVibration() {
  // provide vibraiton feedback
  // **************************
  /*
  Serial.print("3.5 ");
  Serial.println(millis() - now);
  */

  if (combinedChange > threshold) {
    int vibration = map(constrain(combinedChange, 0, 100.0), threshold, 100.0, 80, 254);

    /*
    Serial.print("vibration ");
    Serial.println(vibration);
    */

    analogWrite(vibrationPin, vibration);
    vibrationStart = now;
  } else {
    analogWrite(vibrationPin, 0);
    vibrationStart = 0;
  }
  
  /*
  Serial.print("4 ");
  Serial.println(millis() - now);
  */
}

void setLeds() {

  // leds
  // ****

  // roll: 90 is all up, -90 all down / or reverse if put on the other way around ;)
  // pitch: 90 all left, 90 all right / or reverse on other hand ;)

  // the more the roll is away from 0 (-90 / 90), the less pitch should account for
  // the more the roll is close to 0 the more pitch should account for
  float rollFactor = map(roll, -90.0, 90.0, 0, 200) - 100; // -1.00 - 1.00 (* 100)
  float pitchFactor = map(pitch, -90.0, 90.0, 0, 100); // 0.00 - 1.00 (* 100)

  rollFactor = rollFactor / 100;
  pitchFactor = pitchFactor / 100;

  rollFactor = rollFactor > 0 ? rollFactor : -rollFactor;

  /*
  Serial.println(rollFactor);
  Serial.println(pitchFactor);
  */

  float hue = pitchFactor * (1 - rollFactor) + rollFactor;
  /*
  Serial.print("hue: ");
  Serial.println(hue);
  */

  hue = round(hue * 6) / 6;
  /*
  Serial.print("hue rounded: ");
  Serial.println(hue);
  */

  H2R_HSBtoRGBfloat(hue, 1, 1, &rgbColor[0]);
  setRGBs(rgbColor[0], rgbColor[1], rgbColor[2]);
  /*
  Serial.print(rgbColor[0]);
  Serial.print(", ");
  Serial.print(rgbColor[1]);
  Serial.print(", ");
  Serial.println(rgbColor[2]);
  */
}


void sendJson() {
  /*
  Serial.print("5 ");
  Serial.println(millis() - now);
  */
  String json = "{ \"pitch\": " + String(pitch) +
                ", \"roll\": " + String(roll) +
                ", \"aX\": " + String(accel[0]) +
                ", \"aY\": " + String(accel[1]) +
                ", \"aZ\": " + String(accel[2]) +
                ", \"gX\": " + String(gyro[0]) +
                ", \"gY\": " + String(gyro[1]) +
                ", \"gZ\": " + String(gyro[2]) +
                ", \"rgb\": \"" + rgbColor[0] + "," + rgbColor[1] + "," + rgbColor[2] + "\"" +
                " };";

  // print to bluetooth connection and debug monitor

  /*
  Serial.print("6 ");
  Serial.println(millis() - now);
  */
  // note that I made the observation that if the json wasn't printed to the Serial, it didn't
  // print it to mySerial either... reasons?
  Serial.println(json);
  mySerial.println(json);
  
  /*
  Serial.print("7 ");
  Serial.println(millis() - now);
  */
}


// relay button pressed status to client
void sendButtonDown() {
  String json = "{ buttonDown: 1 }";
  // print to bluetooth connection and debug monitor
  setRGBs(255, 0, 0);
  mySerial.println(json);
  Serial.println(json);
  playSound(6);
}


void readBluetooth() {

  // code for reading IN information from bluetooth
  // read in strings as one until the last ";", then split by colon ":"
  Serial.println(mySerial.available());

  if (mySerial.available() > -1) {
    String bluetoothString = "";
    boolean rec = true;
    while (mySerial.available() && rec) {
      char b = mySerial.read();
      String s = String(b);
      if (s != ";") {
        bluetoothString = bluetoothString + s;
      }
      else {
        rec = false;
      }
    }

    /*
    // expected string something like:
    // roll:12.0,heading:180.29,pitch:123.00;
    String roll = test.substring(0, test.indexOf(":"));
    String heading = test.substring(test.indexOf(":") + 1, test.indexOf("pitch") - 2);
    String pitch = test.substring(test.lastIndexOf(":" + 1));
    */

    String command = bluetoothString.substring(bluetoothString.indexOf(":") + 1, bluetoothString.indexOf(";") - 1);

    Serial.print("Command: ");
    Serial.println(command);

    int soundNumber = -1;

    if (command == "recordingStart") soundNumber = 0;
    if (command == "recordingEnd") soundNumber = 1;
    if (command == "feedbackPerfect") soundNumber = 2;
    if (command == "feedbackGood") soundNumber = 3;
    if (command == "feedbackFail") soundNumber = 4;
    
    if (command == "bluetoothConnected") soundNumber = 7;
    if (command == "bluetoothDisconnected") soundNumber = 8;

    if (soundNumber != -1) {
      playSound(soundNumber);
    }
  }
}

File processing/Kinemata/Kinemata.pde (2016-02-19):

import processing.opengl.*;
import controlP5.*;
import java.lang.RuntimeException;
import java.lang.ArrayIndexOutOfBoundsException;
import java.awt.Color;
import javax.swing.*; 



// null Overlay; when instantiated rendered on top
Overlay overlay;

// wait for uiReady before processing any kind of UI events
// otherwise there will be ControlP5-mayhem
boolean uiReady = false;

// UI elements and helpers on the top level
// NOTE: Each Track() instance has it's own controls
ControlP5 cp5;
Textarea debugText;
int recordingMode = 0;
RadioButton radioMode;

//int lastClick = 0;
//int numClicks = 0;
//int doubleClickThreshold = 1000;

PImage logo;

// The UI and functionality of each device track, here only
// two, but in theory infinite
Track track1;
Track track2;



/**
 * The main processing entry point
 * Set everything up here
 */
void setup() {
  // setup the main UI and rendering
  size(1280, 640, OPENGL);
  setupUI();

  track1 = new Track(this, 10, 150, "First device");
  track2 = new Track(this, 10, 400, "Second device");

  // set to single recording by default
  radioMode(0);

  // render this fast, independent of recording and bluetooth
  // transmission rate (which we set separately
  frameRate(60);

  // get the header image
  logo = loadImage("kinemata.png");

  uiReady = true;
}


/**
 * The main draw loop, running at 60FPS
 * Delegate drawing and updating of components here
 */
void draw() {
  // basic window refresh
  background(221);
  stroke(0);
  image(logo, 10, 10);

  //checkClicks();
  //executeDelayedCommand();

  track1.draw();
  track2.draw();
  
  if (recordingMode == 0) {
    track2.cp5.getGroup("uiFile").hide();    
  } else {
   if (!track2.cp5.getGroup("uiFile").isVisible()) {
      track2.cp5.getGroup("uiFile").show(); 
   }
  }

  //// if there is a overlay, render it
  if (overlay != null) {
   overlay.draw();
  }
}


/**
 * Catch all serial communication and parse what came in
 * Then separate the actions by checking against each Track's
 * connection if this is where it came from
 * Somewhat not ideal delegation here again through the main
 * Processing sketch, but that how it runs
 */
void serialEvent(Serial connection) {
  try {
    //read bluetooth when available
    while (connection.available() > 0) {
      String serialMessage = connection.readString();
      //log(serialMessage);

      // remove any beginning or ending whitespace and (the ending) semicolons
      serialMessage = serialMessage.replaceAll("^[\\s]*", "").replaceAll(";[\\s]*$", "");
      //log("serialMessage", serialMessage);

      // make sure we are actually getting a full string (i.e. with enough commas)
      if (serialMessage.replaceAll("[^,]", "").length() == 8) {

        // do some extra formatting to make the incoming string valid json;
        // the abbreviation from:
        // "{\"p\":13.7,\"r\":3.9,\"aX\":3.7,\"aY\":3.9,\"aZ\":5.6,\"gX\":6.5,\"gY\":17.6,\"gZ\":4.0};"
        // to:
        // "{p13.7,r3.9,aX3.7,aY3.9,aZ5.6,gX6.5,gY17.6,gZ4.0};"
        // reduces send intervals from ~80ms to ~55ms
        // the second string is a sample of what indeed incomming, so remodel it to json
        // THEN: further reduce by removing alphanumericals and "{}"
        // so the string that actually comes in is a list of floats, separated by
        // commas, ending with a semicolon, like this:
        // "13.7,3.9,45,3.7,3.9,5.6,6.5,17.6,4.0;"
        // NOTE: the order of the floats is analog to the order they are sent from
        // Arduino, and this is the order:
        String[] decodeString = {"p", "r", "v", "aX", "aY", "aZ", "gX", "gY", "gZ"};
        String[] parts = new String[8];
        parts = serialMessage.split(",");
        StringBuilder combined = new StringBuilder();
        combined.append("{");
        for (int i = 0; i < parts.length; i++) {
          combined.append(decodeString[i] + ":" + parts[i]);
          if (i < parts.length - 1) {
            combined.append(",");
          }
        }
        combined.append("}");

        // now that we shaped our comma list into a JSON string, parse it for
        // more convenient handling and access
        JSONObject obj = JSONObject.parse(combined.toString());
                
        // check which track the incoming serialEvent belongs to and 
        // forward the parsed data
        if (connection == track1.connection) {
          track1.process(obj);
        } else if (connection == track2.connection) {
          track2.process(obj);
        }
      } else {
        log("Error reading bluetooth: Received bluetooth string, but not a valid string (Number of commas not matching)");
      }
    }
  }
  catch (RuntimeException e) {
    log("Error reading bluetooth: " + e.getMessage());
  }
}


/**
 * UI listener called when the radio button for switching between
 * single track recording and two track recording is clicked
 */
void radioMode(int mode) {
  if (mode == 0) {
    log("Disable separate track recording");
    track1.enableRecordingUI();
    track2.disableRecordingUI();
  } else {
    log("Enable separate track recording");
    track1.enableRecordingUI();
    track2.enableRecordingUI();
  }
  recordingMode = mode;
}



void mainStartRecording(Track track) {
  log("Kinemata.startRecording()");
  if (recordingMode == 0) {
    track1.startRecording();
    track2.startRecording();
  } else {
    track.startRecording();
  }
}

void mainStopRecording(Track track) {
  log("Kinemata.stopRecording()");
  if (recordingMode == 0) {
    track1.stopRecording();
    track2.stopRecording();
  } else {
    track.stopRecording();
  }
}

void mainSaveRecording(Track track) {
  log("Kinemata.saveRecording()");
  if (recordingMode == 0) {
    String filename = track1.getFilename();

    if (track1.recording.getSize() > 0) {
      if (track1.saveData(filename + "-track-1")) {
        log("Track 1 saved");
        track1.clearRecording();
      } else {
        log("Track 1 could not be saved! Try save again or manually clear the recording.");
      }
    } else {
      log("Track 1 empty, nothing to save");
    }

    if (track2.recording.getSize() > 0) {
      if (track2.saveData(filename + "-track-2")) {
        log("Track 2 saved");
        track2.clearRecording();
      } else {
        log("Track 2 could not be saved! Try save again or manually clear the recording.");
      }
    } else {
      log("Track 2 empty, nothing to save");
    }
  } else {
    if (track.recording.getSize() > 0 && 
      track.saveData(track.getFilename())) {
      log("Track saved");
      track.clearRecording();
    } else {
      log("Track could not be saved! Try save again or manually clear the recording.");
    }
  }
}

void mainClearRecording(Track track) {
  log("Kinemata.clearRecording()");
  if (recordingMode == 0) {
    track1.clearRecording();
    track2.clearRecording();
  } else {
    track.clearRecording();
  }
}
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

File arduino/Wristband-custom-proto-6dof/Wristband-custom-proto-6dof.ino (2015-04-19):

#include <HSBColor.h>
#include <SPI.h>
#include <SFE_LSM9DS0.h>
#include <SoftwareSerial.h>
#include <Wire.h>

// driver for the led pwm module
#include <Adafruit_PWMServoDriver.h>

// the 6DoF module's libraries
#include <FreeSixIMU.h>
#include <FIMU_ADXL345.h>
#include <FIMU_ITG3200.h>

// defined shortcuts for notes with common musical names
#include "pitches.h"

// called this way, it uses the default address 0x40
Adafruit_PWMServoDriver pwm = Adafruit_PWMServoDriver(0x40);
// you can also call it with a different address you want
//Adafruit_PWMServoDriver pwm = Adafruit_PWMServoDriver(0x41);

const int baudrate = 9600;

const int rx = 7;
const int tx = 8;
SoftwareSerial mySerial(rx, tx);

const int onBoardLedPin = 6;
const int vibrationPin = 5;
const int buzzerPin = 11;

int data[2];
int serialIndex = 0;

int lastRotation = 0;

int lastR = 0;
int lastG = 100;
int lastB = 200;

int lastRoll = 0;
int lastHeading = 0;
int lastPitch = 0;

float easing = 0.5; // 0 - 1 as factor of "last frame reading" impact on new reading


float angles[3]; // yaw pitch roll

// Set the FreeSixIMU object
FreeSixIMU dof = FreeSixIMU();

int notes[] = {
  NOTE_C4,
  NOTE_D4,
  NOTE_E4,
  NOTE_F4,
  NOTE_G4,
  NOTE_A4,
  NOTE_B4,
};


// custom pcb led channels for pwm library access
// led numbers with USB connector facing toward you, left top is 1, then clockwise
// note that with 4 leds a 3 channels not all 16 pwm channels are used
const int led1R = 14;
const int led1G = 15;
const int led1B = 13;

const int led2R = 10;
const int led2G = 11;
const int led2B = 9;

const int led3R = 7;
const int led3G = 8;
const int led3B = 6;

const int led4R = 4;
const int led4G = 5;
const int led4B = 3;


void setup ()
{
  Serial.begin(9600);
  Serial.println("hello serial");
  mySerial.begin(baudrate);

  Wire.begin();

  delay(5);
  dof.init(); //begin the IMU
  delay(5);

  // adafruit pwm driver
  pwm.begin();
  pwm.setPWMFreq(1600);  // This is the maximum PWM frequency
  // save I2C bitrate
  uint8_t twbrbackup = TWBR;
  // must be changed after calling Wire.begin() (inside pwm.begin())
  TWBR = 12; // upgrade to 400KHz!

  analogWrite(onBoardLedPin, LOW);

}

String test = "";

float lastHue = 0;
float lastSaturation = 0;
float lastBrightness = 1;

int rgbColor[3];
int lastVibration = 0;

int note = 0;
int lastNote = 0;
int lastNoteStarted = 0;

/*
RGBConverter col = RGBConverter();
*/

void loop ()
{

  // reading bluetooth
  // =================

  // code for reading IN information from bluetooth
  // this will be used for "playback" mode
  // read in strings as one until the last ";", then split by colon ":"
  if (mySerial.available() > -1) {
    test = "";
    boolean rec = true;
    while (mySerial.available() && rec) {
      char b = mySerial.read();
      String s = String(b);
      if (s != ";") {
        test = test + s;
      }
      else {
        rec = false;
      }
    }
    // expected string something like:
    // roll:12.0,heading:180.29,pitch:123.00;
    String roll = test.substring(0, test.indexOf(":"));
    String heading = test.substring(test.indexOf(":") + 1, test.indexOf("pitch") - 2);
    String pitch = test.substring(test.lastIndexOf(":" + 1));

    Serial.println(roll + " " + heading + " " + pitch);
  }


  // reading sensors
  // ===============

  // calculate new readings from sensor and ease them from last values
  dof.getYawPitchRoll(angles);

  float headingReading = angles[0];
  float pitchReading = angles[1];
  float rollReading = angles[2];

  float heading = lastHeading * easing + (1 - easing) * headingReading;

  // these will range from -45 to 45
  // easing defines the portion of the previous value that is blended with
  // the new reading, thus easing the value to be less jumpy for drastic changes
  float pitch = lastPitch * easing + (1 - easing) * pitchReading;
  float roll = lastRoll * easing + (1 - easing) * rollReading;
  
  // get the raw values of accelerometer (index 0-2) and magnetometer (index 3-5)
  float values[6];
  dof.getValues(values);


  // calculate some values for feedback from current sensor readings

  float newHue = map(roll, -45, 45, 0, 100.0) / 100.0;
  float hueDifference = lastHue - newHue;
  float headingDifference = lastHeading - heading;


  // play notes on movement
  // ======================

  //Serial.println(headingDifference);
  //Serial.println(heading);

  if (abs(headingDifference) > 5) {
    int noteIndex = map(headingDifference, -90, 90, 0, 6);
    note = notes[noteIndex];
    //Serial.println("new note");
    //Serial.println(note);
  }

  if (lastNoteStarted == 0 || lastNoteStarted > millis() + 1000 / 3) {
    if (note > 0 && note != lastNote) {
      Serial.println("play new note");
      tone(buzzerPin, note, 1000 / 3);
      lastNote = note;
    }
  }




  // coloring the leds of the device
  // ===============================

  // get rgb value from hsl
  H2R_HSBtoRGBfloat(newHue, 1, 1, &rgbColor[0]);

  // store the current color for comparison on next loop
  lastHue = newHue;

  setRGBs(rgbColor[0], rgbColor[1], rgbColor[2]);

  /*
  Serial.println(rgbColor[0]);
  Serial.println(rgbColor[1]);
  Serial.println(rgbColor[2]);
  */


  // giving vibration feedback
  // =========================
  // abs() does a bit weird things, so tenary abs() and * 100 in one
  hueDifference = hueDifference < 0 ? hueDifference * -100 : hueDifference * 100;
  // * 5 to amplify difference value => sensitiviy
  hueDifference = constrain(hueDifference * 2, 0, 100);
  int vibration = map(hueDifference, 0, 100, 0, 255);
  if (vibration > 125) {
    analogWrite(vibrationPin, vibration);
  } else {
    // while vibration is under the threshold of triggering a forceful sensation
    // fade it out so the previous peek is perceived more smooth and fades out
    // when under bottom threshold of barely perceiveable vibration, set to 0
    // to save battery
    if (lastVibration > 75) {
      vibration = constrain(lastVibration * 0.75, 0, 255);
    } else {
      vibration = 0;
    }
    analogWrite(vibrationPin, vibration);
  }

  // store this vibration impulse for possible fading out in next loop
  lastVibration = vibration;




  // interval at which to send and receive from bluetooth, 24fps
  delay(1000 / 24);

  noTone(buzzerPin);

  lastHeading = heading;
  lastPitch = pitch;
  lastRoll = roll;
  
  
  
  
  String p = "{ heading: " + String(heading) +
             ", pitch: " + String(pitch) +
             ", roll: " + String(roll) + 
             ", accelX: " + String(values[0]) +
             ", accelY: " + String(values[1]) +
             ", accelZ: " + String(values[2]) +
             ", gyroX: " + String(values[3]) +
             ", gyroY: " + String(values[4]) +
             ", gyroZ: " + String(values[5]) +
             ", rgb: \"" + rgbColor[0] + "," + rgbColor[1] + "," + rgbColor[2] + "\""
             " };";

  // print to bluetooth connection and debug monitor
  mySerial.println(p);
  //Serial.println(p);
}
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

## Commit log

2015-03-04 added rather messy wip arduino sketch
2015-03-07 added two arduino sketches that are useful for testing out the i2c setup
2015-03-07 switched proto to use rgb leds via i2c adafruit pwm library
2015-03-08 added first wip version of the custom led shield pcb design
    [ledshield.brd, ledshield.sch]
2015-03-11 bluetooth device dropdownlist picker wip
2015-03-15 added fixed exampl eagle design and created second version of ledshield
    [ledshield_v1_michihito.brd, ledshield_v1_michihito.sch, ledshield_v2.brd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]
2015-03-15 added bluetooth connection UI to pick device from list
2015-03-16 updated led shield design with common ground and passing design and electrical checks also started bluetooth/arduino communication to work in reverse from processing to arduino
    [ledshield_v2.brd, ledshield_v2.sch]
2015-03-18 code cleanup, indentation fixes, comments
    [ColorCube.pde, Grapher.pde, Wristband.pde]
2015-03-18 fixed two missing declarations
    [Wristband.pde]
2015-03-30 added visualization wrapper that opens fullscreen on button press
2015-03-31 added 3d object to visualization example for further dev with actual 3d model included
    [dma.obj]
2015-04-15 addde new arduino code based on custom lilypad + pcb and with 6dof only for now
2015-04-16 a lot more work on the 6dof proto; lights responding to roll, buzzer giving heading feedback
    [Wristband-custom-proto-6dof.ino]
2015-04-23 added second version PCB design files
    [leds.brd, leds.sch, leds_9dof.brd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]
2015-04-27 modified 2nd version pcb designs for milling
    [leds_9dof.brd, leds_9dof_2.brd, leds_9dof_2.sch]
2015-05-11 started second custom PCB arduino code
    [leds.brd, leds.sch]
2015-05-11 added second custom PCB milling files to repo still
2015-05-11 retrospectively added milling files of 1st PCB
2015-05-13 more ground work for custom PCB version #2
2015-05-13 sensor readings are now interpreted as percentual change in respect to last reading; also, the min max values adjust dynamically to new peaks
2015-05-14 vibration based feedback, with fps compensation
    [Wristband-custom-proto.ino]
2015-05-14 color based on pitch and roll, kind of working, but with weird reset exception on extremes
    [Wristband-custom-proto.ino]
2015-05-14 added basic button via bluetooth commands to processing
2015-05-15 added test arduino sketch for testing feedback sounds
2015-05-17 vibration with interrupt, loop and sensor read separation
    [Wristband-custom-proto.ino]
2015-05-26 more code cleanup, arduino
2015-05-26 added startup and button sound
2015-05-26 some fixes, arduino and processing now work
    [Wristband-custom-proto.ino, Wristband.pde]
2015-05-26 splitting up arduino loop to distribute duties within fps more evenly - WIP
2015-05-26 more work on splitting the arduino loop more evenly
2015-05-26 working with much faster sensor read loop
2015-05-27 similarity kind of not working due to too slow or missin json sends from bluetooth
    [Wristband.pde]
2015-05-27 demo buttons for video feedback
2015-05-27 added somewhat unreliably working physical button recording
2015-05-27 some button styling
2015-05-27 fixed rotation display, and idle animation to be more random, cube sides coloring
    [ColorCube.pde, Wristband.pde]
2015-05-27 fixed top graph not working
    [Wristband.pde]
2015-05-27 update graphs during recording of either track
2015-05-27 recording visual highlight on frame of the respective track
2015-05-27 added some missing arduino files and an arduino buzzer sound testing example
    [DoF.ino, Leds.ino, Sounds.ino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]
2015-09-25 started work on new custom board
    [IoT_modules_atmega328_kinemata_v1.brd, IoT_modules_atmega328_kinemata_v1.sch]
2015-09-25 some more initial work on the custom PCB
    [110mAhBattery.dxf, IoT_modules_atmega328_kinemata_v1.brd, IoT_modules_atmega328_kinemata_v1.sch]
2015-09-29 custom pcb further routed
    [IoT_modules_atmega328_kinemata_v2.brd, IoT_modules_atmega328_kinemata_v2.sch]
2015-09-30 custom PCB wiring technically done, DRC ok
    [IoT_modules_atmega328_kinemata_v2.brd, IoT_modules_atmega328_kinemata_v2.sch]
2015-10-05 0.012 wiring almost done
    [IoT_modules_atmega328_kinemata_v3.brd, IoT_modules_atmega328_kinemata_v3.sch]
2015-10-06 custom pcb wiring passing drc
    [IoT_modules_atmega328_kinemata_v3.brd, IoT_modules_atmega328_kinemata_v3.sch]
2015-10-12 tweaked positioning and minor issues on custom PCB
    [IoT_modules_atmega328_kinemata_v3.brd]
2015-10-21 custom pcb pre print
    [IoT_modules_atmega328_kinemata_v3.brd]
2016-01-25 some cleanup
    [IoT_modules_atmega328_kinemata_v3.brd, IoT_modules_atmega328_kinemata_v3.sch]
2016-01-25 added some arduino helpers
2016-01-25 added second version led shields
    [leds_9dof_michi.brd, leds_9dof_michi.sch]
2016-01-25 added eagle design files for v4 prototype PCB
    [IoT_modules_atmega328_kinemata_v1.brd, IoT_modules_atmega328_kinemata_v2.sch, kinemata.brd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]
2016-01-25 added 3d design files for kinemata v4
2016-01-25 arduino code for v4 started
2016-01-25 renamed current WIP files to Kinemata for each part of the project
    [110mAhBattery.dxf, kinemata.brd, kinemata.sch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]
2016-01-25 arduino to processing BT working for one device; new processing UI started
2016-01-26 added missing sliders to ui, not hooked up to bluetooth data yet
    [Track.pde]
2016-01-27 more work on bluetooth connection and handling; improvement to raw send speed from Arduino to Processing
2016-01-28 slightly tweaked 3d modle for bottom - screw positioning
2016-02-14 some fixes for 3.0.2 and checkboxes wip
    [Grapher.pde, Kinemata.pde, Track.pde]
2016-02-14 added button icons
    [dma.obj]
2016-02-14 button highlight for unsaved recording
2016-02-15 fixed error in slider checkbox and made both tracks responsive to respective checkboxes
    [Kinemata.pde]
2016-02-16 added vibration to data json and fixed file save csv data ordering bug
    [Kinemata.ino, Kinemata.pde, Overlay.pde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]
2016-02-16 added BT dps meter and improved arduino FPS slightly
2016-02-16 small arduino ammend
2016-02-17 Added method call delegator (Processing workaround) and a bunch of code commenting, esp. Kinemata.pde
    [Kinemata.pde, Track.pde]
2016-02-17 recording state button changes and filename checks
2016-02-18 implemented recording same consecutive frames as empty, slider colors match grapher
2016-02-18 fixed bluetooth connecting overlay rendering
    [Kinemata.pde, Overlay.pde, Track.pde]
2016-02-19 inverted pitch and roll on sensor side - the sensor in the new version is oriented differentlygit status
    [Kinemata.ino, Kinemata.pde, Overlay.pde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]
2016-02-19 fixed button unresponsive / layering issue
    [Recording.pde, Track.pde]
2016-02-19 couple of obvious fixes to separate track recording mode
    [Kinemata.pde, Track.pde]
2016-02-20 fixed the implemented pitch/roll reverse to not affect light calculations, also removed any serial.prints on device which further sped up the processing
    [Kinemata.ino]
2016-02-20 fixed connection FPS display
    [Track.pde]

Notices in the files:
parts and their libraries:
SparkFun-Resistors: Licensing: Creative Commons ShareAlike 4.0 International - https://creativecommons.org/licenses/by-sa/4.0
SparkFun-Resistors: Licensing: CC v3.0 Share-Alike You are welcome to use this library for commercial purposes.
